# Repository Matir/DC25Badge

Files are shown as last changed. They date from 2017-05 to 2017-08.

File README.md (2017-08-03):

## Matir's DEF CON 25 Badge ##

This is an unofficial badge I made for DEF CON 25.  It's a blinding party-style
badge with 48 individually addressable RGB LEDs.  Off an adequate battery (a
medium LiPo) you can run all lights at max brightness, but that is *bright*.

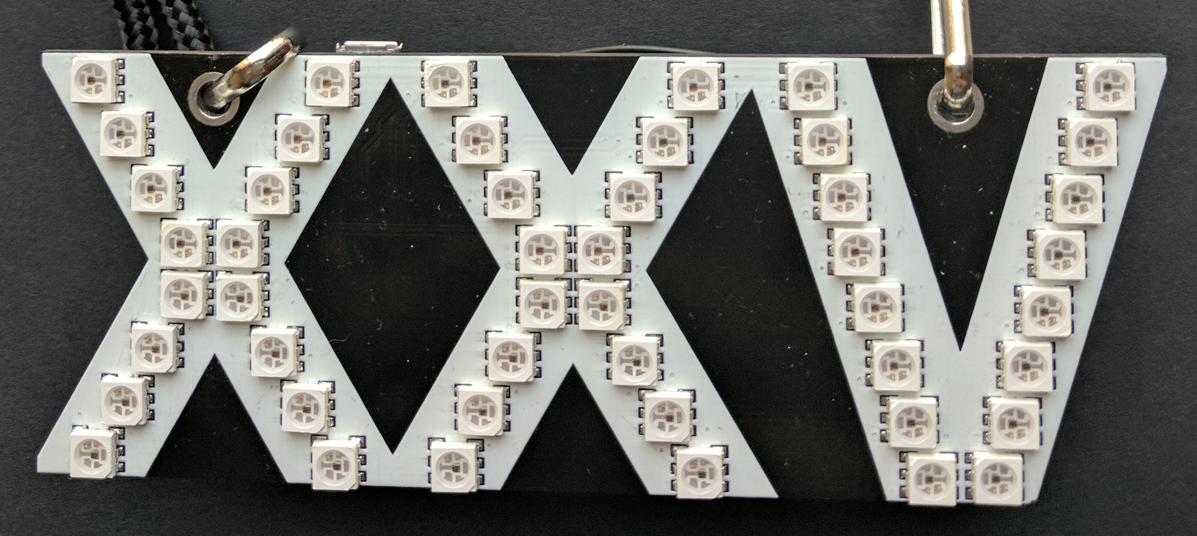
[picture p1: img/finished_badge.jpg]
Finished Badge


This is intended as a one-time release for others to learn from and/or remix the
firmware.  I don't plan to take pull requests since it will be over and I'll be
on to another project by the release.  :)

### PCB ###

The PCB was designed using Kicad.  Source files are in the `dc25badge/`
directory.

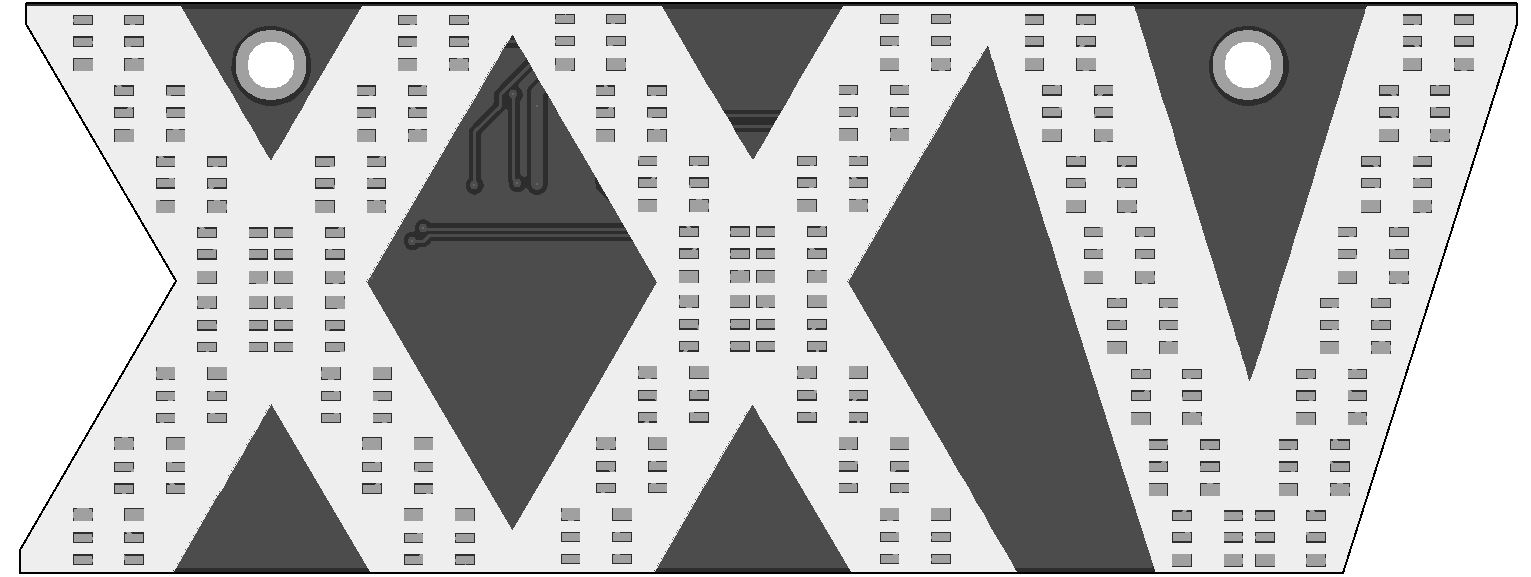
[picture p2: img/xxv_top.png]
PCB Rendering


### Compiling Firmware ###

To build the firmware, you'll need 3 things: this git repository, the Atmel
Software Framework (ASF), and an ARM compiler.  On Debian & Ubuntu, you'll want
to install the packages `gcc-arm-none-eabi` and `binutils-arm-none-eabi`.

`setup.sh` in the `src/` directory will get you the latest build of the ASF (at
least, it worked when this was prepared).  Running `make` will build the
firmware image.

To choose which patterns are available by pushing the mode button, edit the
array in `pattern.c`.

### Uploading Firmware ###

To upload a firmware image, you'll need to get into the bootloader.  To do this,
"double tap" the reset button, and the reset LED will stay solid green.  (If it
doesn't, you're not in the bootloader.)

You can then use `bossa` or just run `make upload` from the `src/` directory to
upload the current firmware build.

This is not an official Google product.

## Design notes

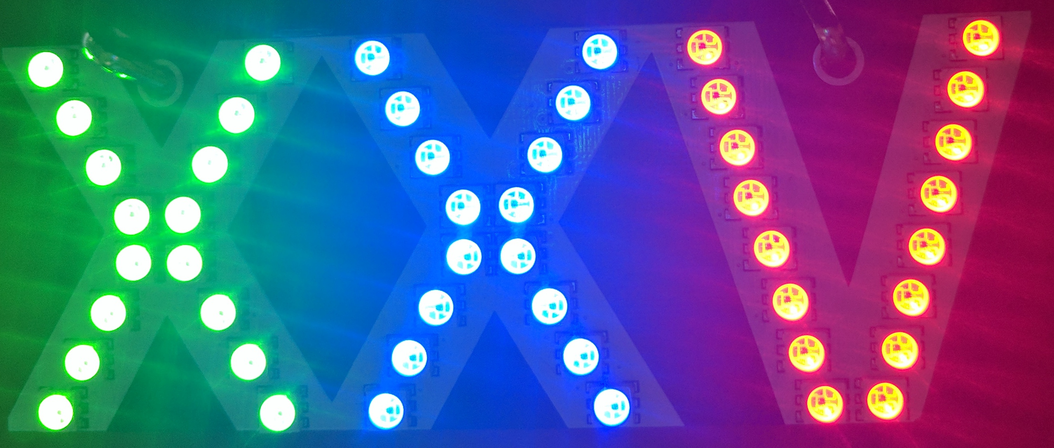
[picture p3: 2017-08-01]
img/lit_grb.jpg

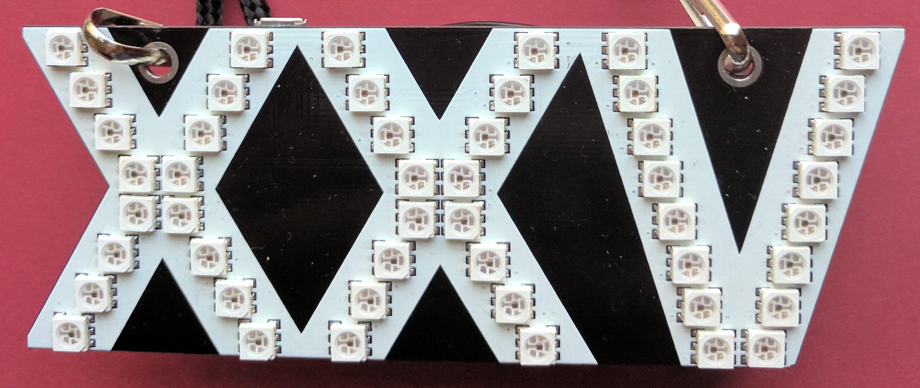
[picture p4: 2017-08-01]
img/finished_red.jpg

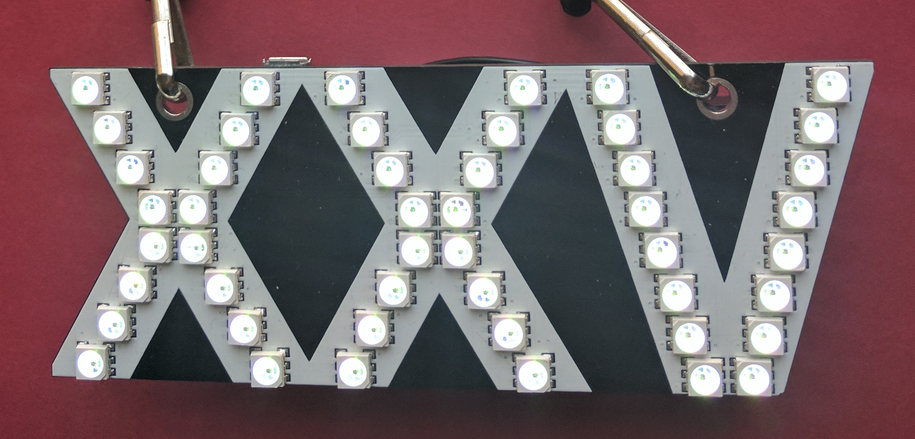
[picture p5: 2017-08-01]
img/lit_white.jpg

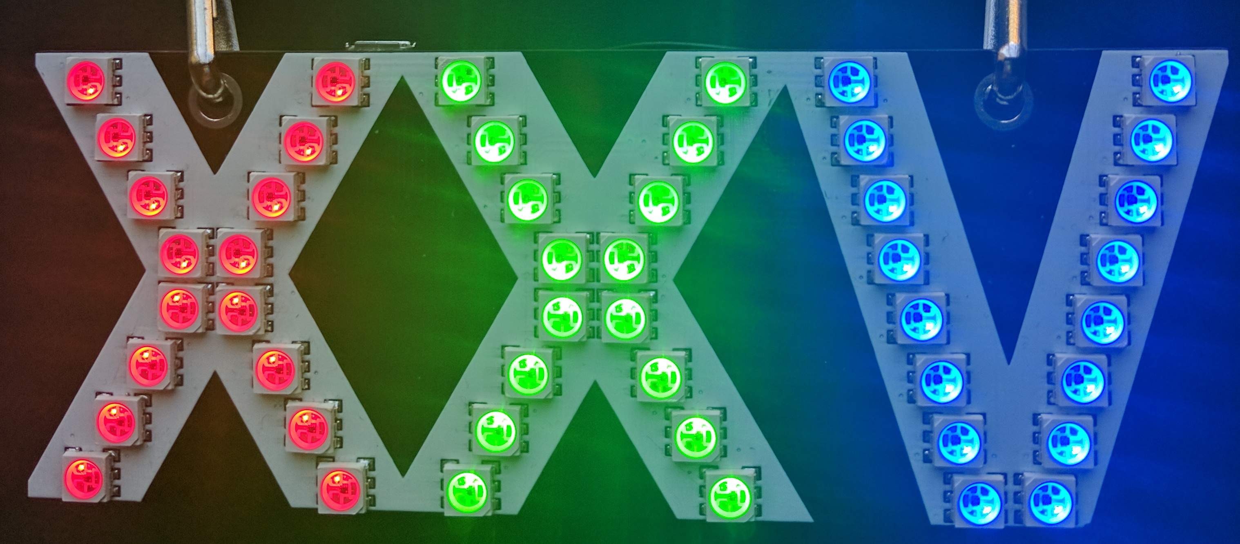
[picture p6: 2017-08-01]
img/lit_rgb.jpg

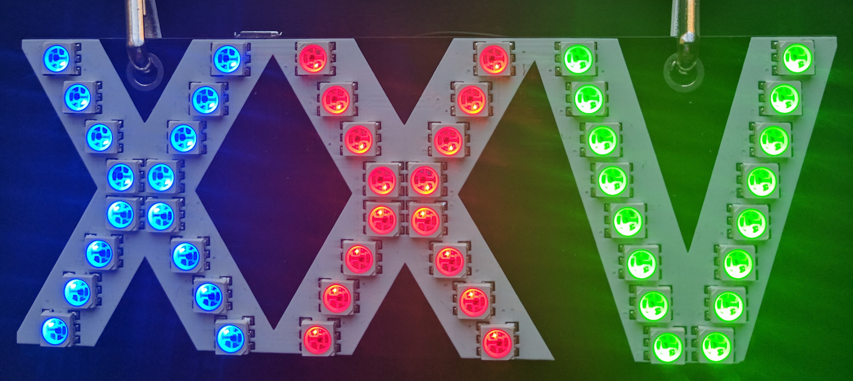
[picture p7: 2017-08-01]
img/lit_brg.jpg

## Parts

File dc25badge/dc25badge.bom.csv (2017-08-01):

Reference | Value | Footprint | Datasheet
U1 | MIC5305 | TO_SOT_Packages_SMD:SOT-23-5
P1 | BATT | Connectors_JST:JST_PH_S2B-PH-SM4-TB_02x2.00mm_Angled
C2 | 0.1u | Capacitors_SMD:C_0805
C1 | 1u | Capacitors_SMD:C_0805
C3 | 1u | Capacitors_SMD:C_0805
U3 | ATSAMD21E18A-AU | Housings_QFP:TQFP-32_7x7mm_Pitch0.8mm
C7 | 0.1u | Capacitors_SMD:C_0805
C9 | 0.1u | Capacitors_SMD:C_0805
C10 | 0.1u | Capacitors_SMD:C_0805
R6 | 10k | Resistors_SMD:R_0805
C11 | 10u | Capacitors_SMD:C_0805
C8 | 0.1u | Capacitors_SMD:C_0805
R5 | 330 | Resistors_SMD:R_0805
SW1 | RESET | Buttons_Switches_SMD:SW_SPST_EVQP0
P3 | CORTEX | Pin_Headers2:Pin_Header_Straight_2x05_Pitch1.27mm_SMD
P2 | USB_OTG | Badge_Parts:Amphenol_10118192
U4 | 74AHCT125 | SMD_Packages:SOIC-14_N
W2 | 3v3 | Measurement_Points:Measurement_Point_Round-SMD-Pad_Big
W3 | 5v | Measurement_Points:Measurement_Point_Round-SMD-Pad_Big
Y1 | 32.768k | Crystals:Crystal_SMD_G8
C13 | 22pF | Capacitors_SMD:C_0603
C12 | 22pF | Capacitors_SMD:C_0603
SW3 | MODE | Buttons_Switches_SMD:SW_SPST_EVQP0
SW4 | BRIGHT | Buttons_Switches_SMD:SW_SPST_EVQP0
U2 | TPS61232 | Badge_Parts:PSON-10P
C5 | 0.1u | Capacitors_SMD:C_0805
L1 | 1uH | Badge_Parts:Inductor_6.5x6
C4 | 22u | Capacitors_SMD:C_0805
C6 | 22u | Capacitors_SMD:C_0805
C14 | 22u | Capacitors_SMD:C_0805
C27 | 22u | Capacitors_SMD:C_0805
R1 | 330 | Resistors_SMD:R_0805
D1 | LED | LEDs:LED_0805
Q1 | DMN1019USN | TO_SOT_Packages_SMD:SOT-23
C17 | 1u | Capacitors_SMD:C_0805
R2 | 330 | Resistors_SMD:R_0805
R3 | 330 | Resistors_SMD:R_0805
C23 | NP | Capacitors_SMD:C_0805
C28 | NP | Capacitors_SMD:C_0805
JP1 | Jumper_NO_Small | Badge_Parts:JP_SOLDER
U38 | APA102 | Badge_Parts:APA102
U44 | APA102 | Badge_Parts:APA102
U50 | APA102 | Badge_Parts:APA102
U56 | APA102 | Badge_Parts:APA102
U14 | APA102 | Badge_Parts:APA102
U20 | APA102 | Badge_Parts:APA102
U26 | APA102 | Badge_Parts:APA102
U32 | APA102 | Badge_Parts:APA102
U29 | APA102 | Badge_Parts:APA102
U23 | APA102 | Badge_Parts:APA102
U17 | APA102 | Badge_Parts:APA102
U11 | APA102 | Badge_Parts:APA102
U53 | APA102 | Badge_Parts:APA102
U47 | APA102 | Badge_Parts:APA102
U41 | APA102 | Badge_Parts:APA102
U35 | APA102 | Badge_Parts:APA102
U39 | APA102 | Badge_Parts:APA102
U45 | APA102 | Badge_Parts:APA102
U51 | APA102 | Badge_Parts:APA102
U57 | APA102 | Badge_Parts:APA102
U15 | APA102 | Badge_Parts:APA102
U21 | APA102 | Badge_Parts:APA102
U27 | APA102 | Badge_Parts:APA102
U33 | APA102 | Badge_Parts:APA102
U30 | APA102 | Badge_Parts:APA102
U24 | APA102 | Badge_Parts:APA102
U18 | APA102 | Badge_Parts:APA102
U12 | APA102 | Badge_Parts:APA102
U54 | APA102 | Badge_Parts:APA102
U48 | APA102 | Badge_Parts:APA102
U42 | APA102 | Badge_Parts:APA102
U36 | APA102 | Badge_Parts:APA102
U40 | APA102 | Badge_Parts:APA102
U46 | APA102 | Badge_Parts:APA102
U52 | APA102 | Badge_Parts:APA102
U58 | APA102 | Badge_Parts:APA102
U64 | APA102 | Badge_Parts:APA102
U22 | APA102 | Badge_Parts:APA102
U28 | APA102 | Badge_Parts:APA102
U34 | APA102 | Badge_Parts:APA102
U31 | APA102 | Badge_Parts:APA102
U25 | APA102 | Badge_Parts:APA102
U19 | APA102 | Badge_Parts:APA102
U61 | APA102 | Badge_Parts:APA102
U55 | APA102 | Badge_Parts:APA102
U49 | APA102 | Badge_Parts:APA102
U43 | APA102 | Badge_Parts:APA102
U37 | APA102 | Badge_Parts:APA102
C15 | 0.1u | Capacitors_SMD:C_0805
C16 | 0.1u | Capacitors_SMD:C_0805
C18 | 0.1u | Capacitors_SMD:C_0805
C19 | 0.1u | Capacitors_SMD:C_0805
C20 | 0.1u | Capacitors_SMD:C_0805
C21 | 0.1u | Capacitors_SMD:C_0805
C22 | 0.1u | Capacitors_SMD:C_0805
C24 | 0.1u | Capacitors_SMD:C_0805
C25 | 0.1u | Capacitors_SMD:C_0805
C26 | 0.1u | Capacitors_SMD:C_0805

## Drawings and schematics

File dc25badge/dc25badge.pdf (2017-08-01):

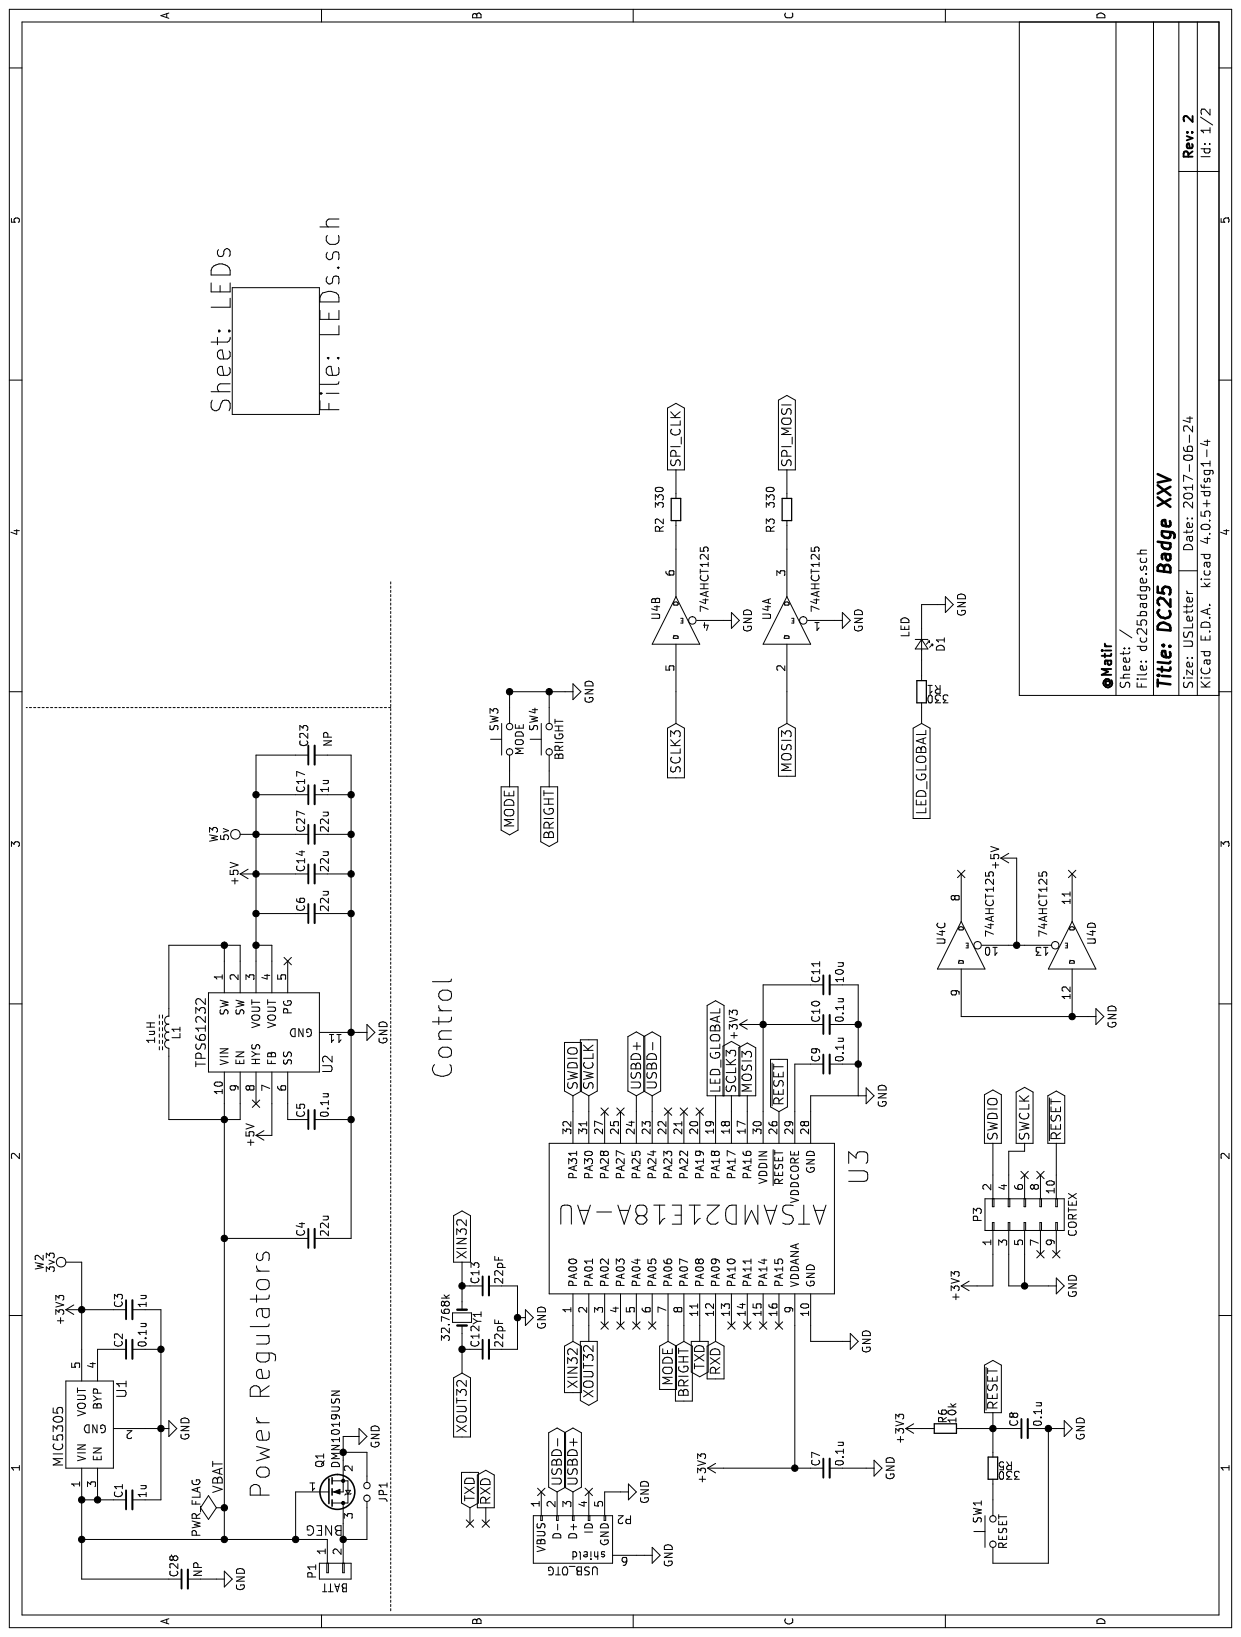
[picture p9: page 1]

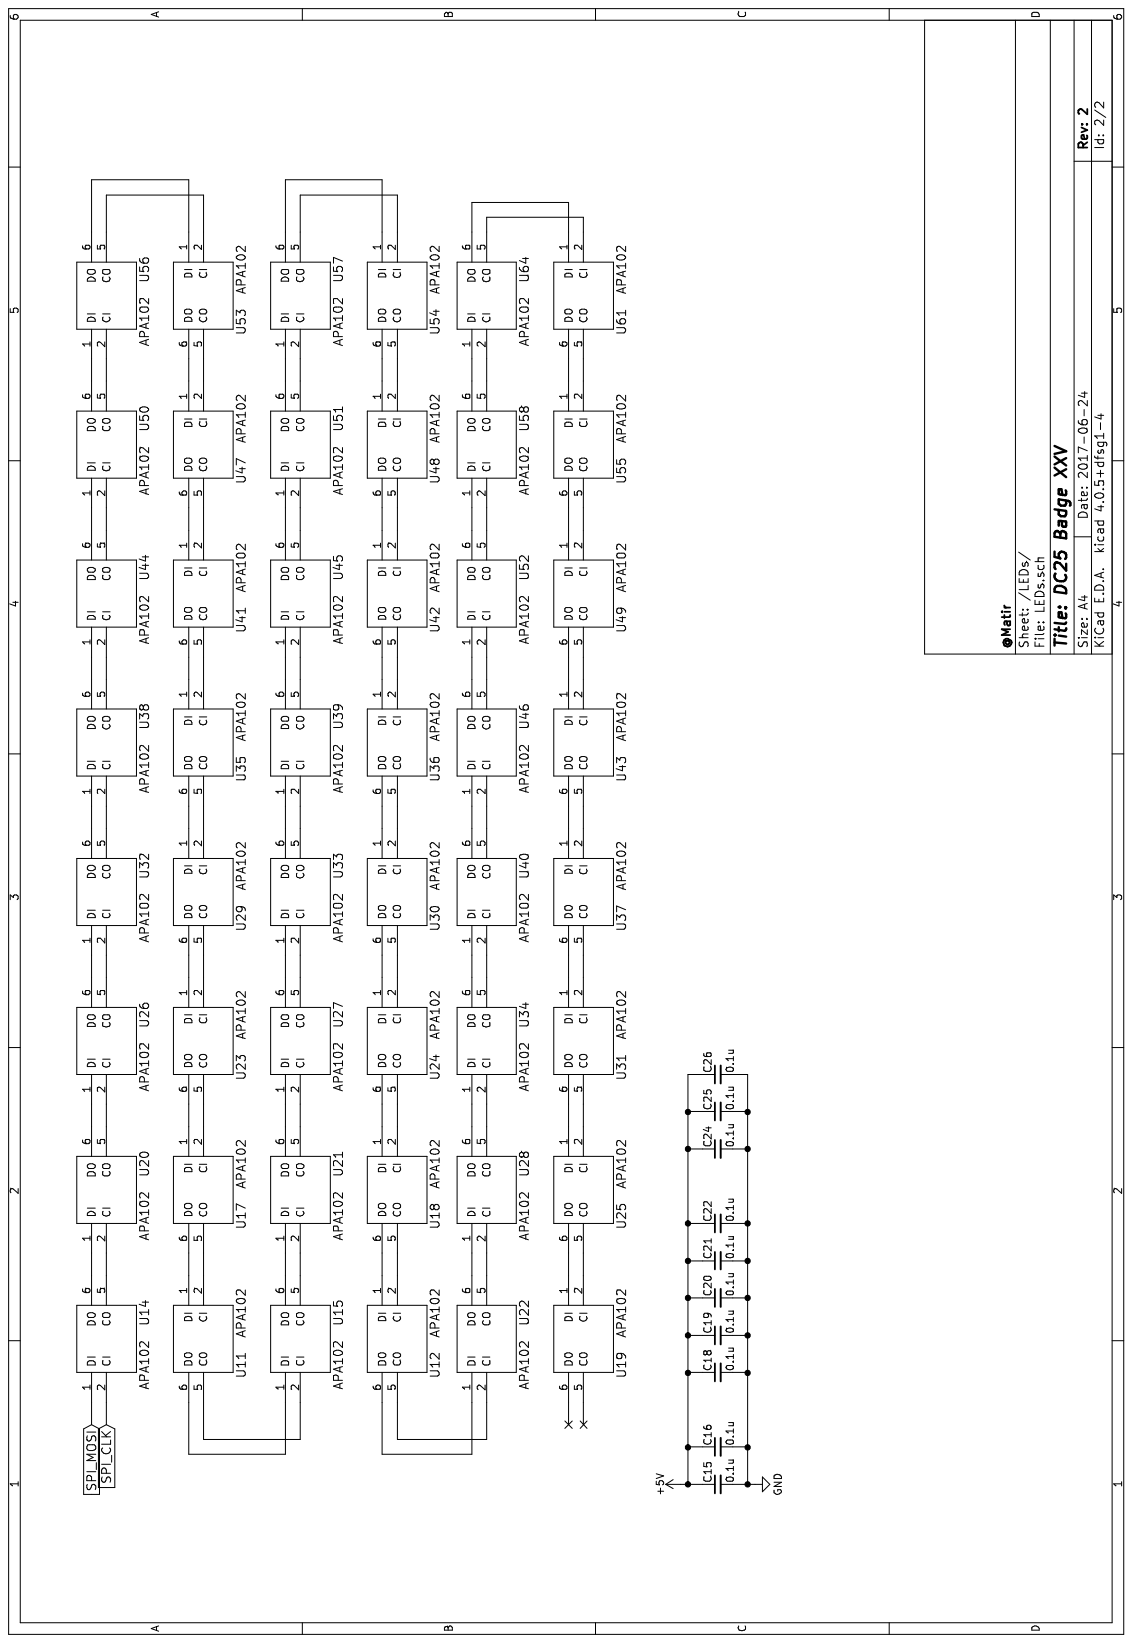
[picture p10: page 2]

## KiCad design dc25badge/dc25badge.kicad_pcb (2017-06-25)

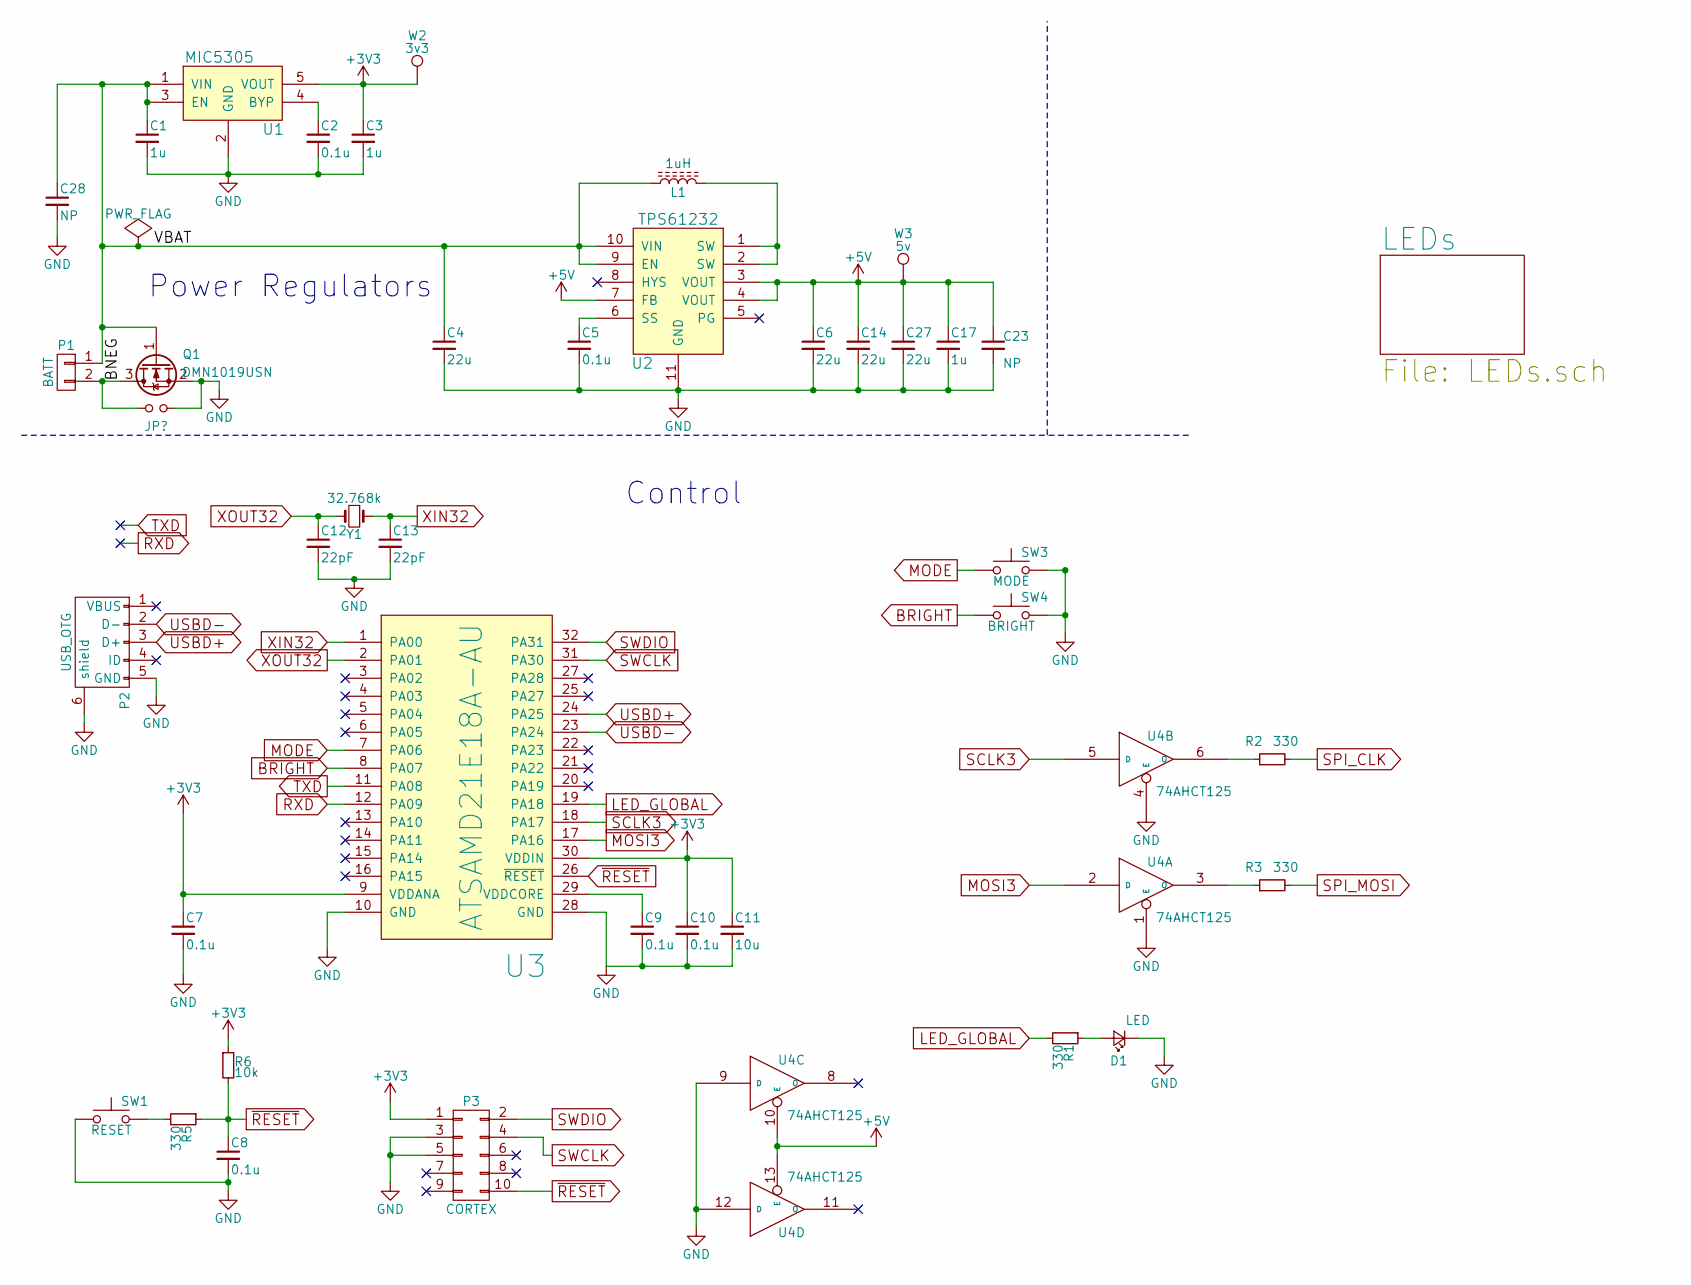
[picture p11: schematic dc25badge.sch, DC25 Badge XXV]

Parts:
C1, C3, C17: 1u; C_0805
C2, C5, C7, C8, C9, C10: 0.1u; C_0805
C4, C6, C14, C27: 22u; C_0805
C11: 10u; C_0805
C12, C13: 22pF; C_0603
C23, C28: NP; C_0805
D1: LED; LED_0805
L1: 1uH; Inductor_6.5x6
P1: BATT; JST_PH_S2B-PH-SM4-TB_02x2.00mm_Angled
P2: USB_OTG; Amphenol_10118192
P3: CORTEX; Pin_Header_Straight_2x05_Pitch1.27mm_SMD
Q1: DMN1019USN; SOT-23
R1, R2, R3, R5: 330; R_0805
R6: 10k; R_0805
SW1: RESET; SW_SPST_EVQP0
SW3: MODE; SW_SPST_EVQP0
SW4: BRIGHT; SW_SPST_EVQP0
U1: MIC5305; SOT-23-5
U2: TPS61232; PSON-10P
U3: ATSAMD21E18A-AU; TQFP-32_7x7mm_Pitch0.8mm
U4: 74AHCT125; SOIC-14_N
W2: 3v3; Measurement_Point_Round-SMD-Pad_Big
W3: 5v; Measurement_Point_Round-SMD-Pad_Big
Y1: 32.768k; Crystal_SMD_G8

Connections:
+3V3: C3.1, C7.1, C10.1, C11.1, P3.1, R6.1, U1.5 (VOUT), U3.9 (VDDANA), U3.30 (VDDIN), W2.1
+5V: C6.1, C14.1, C17.1, C23.1, C27.1, U2.3 (VOUT), U2.4 (VOUT), U2.7 (FB), U4.10 (E), U4.13 (E), U4.14 (+5V), W3.1; also elsewhere on the board
/BNEG: P1.2, Q1.3 (D); also elsewhere on the board
/VBAT: C1.1, C4.1, C28.1, L1.1, P1.1, Q1.1 (G), U1.1 (VIN), U1.3 (EN), U2.9 (EN), U2.10 (VIN)
BRIGHT: SW4.1, U3.8 (PA07)
GND: C1.2, C2.2, C3.2, C4.2, C5.2, C6.2, C7.2, C8.2, C9.2, C10.2, C11.2, C12.2, C13.2, C14.2, C17.2, C23.2, C27.2, C28.2, D1.1 (K), P2.5 (GND), P2.6 (shield), P3.3, P3.5, Q1.2 (S), SW1.1, SW3.2, SW4.2, U1.2 (GND), U2.11 (GND), U3.10 (GND), U3.28 (GND), U4.1 (E), U4.4 (E), U4.7 (GND), U4.9 (D), U4.12 (D); also elsewhere on the board
LED_GLOBAL: R1.2, U3.19 (PA18)
MODE: SW3.1, U3.7 (PA06)
MOSI3: U3.17 (PA16), U4.2 (D)
unnamed: C2.1, U1.4 (BYP)
unnamed: C5.1, U2.6 (SS)
unnamed: C9.1, U3.29 (VDDCORE)
unnamed: D1.2 (A), R1.1
unnamed: L1.2, U2.1 (SW), U2.2 (SW)
unnamed: R2.1, U4.6 (O)
unnamed: R3.1, U4.3 (O)
unnamed: R5.2, SW1.2
RXD: U3.12 (PA09)
SCLK3: U3.18 (PA17), U4.5 (D)
SPI_CLK: R2.2; also elsewhere on the board
SPI_MOSI: R3.2; also elsewhere on the board
SWCLK: P3.4, U3.31 (PA30)
SWDIO: P3.2, U3.32 (PA31)
TXD: U3.11 (PA08)
USBD+: P2.3 (D+), U3.24 (PA25)
USBD-: P2.2 (D-), U3.23 (PA24)
XIN32: C13.1, U3.1 (PA00), Y1.1
XOUT32: C12.1, U3.2 (PA01), Y1.2
~RESET: C8.1, P3.10, R5.1, R6.2, U3.26 (~RESET)

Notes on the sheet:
Power Regulators
Control

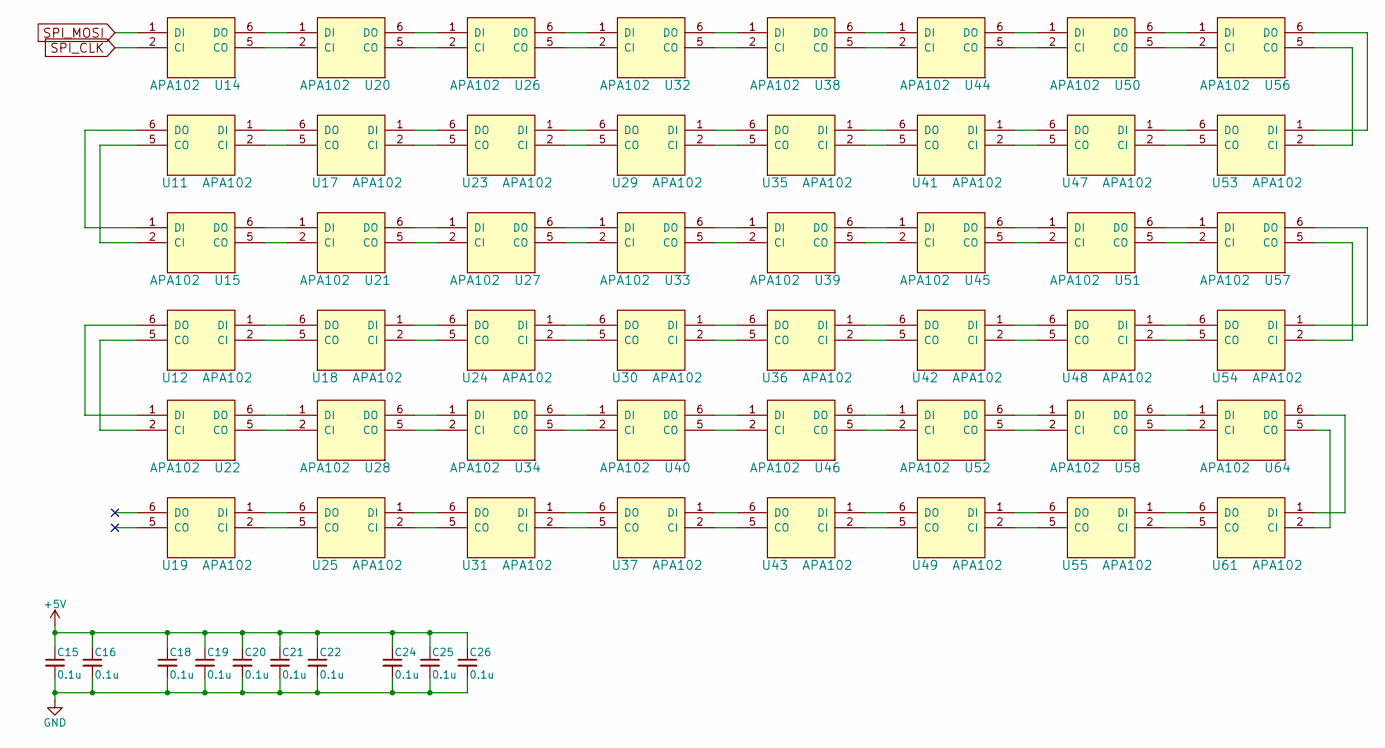
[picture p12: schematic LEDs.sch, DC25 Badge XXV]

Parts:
C15, C16, C18, C19, C20, C21, C22, C24, C25, C26: 0.1u; C_0805
U11, U12, U14, U15, U17, U18, U19, U20, U21, U22, U23, U24, U25, U26, U27, U28, U29, U30, U31, U32, U33, U34, U35, U36, U37, U38, U39, U40, U41, U42, U43, U44, U45, U46, U47, U48, U49, U50, U51, U52, U53, U54, U55, U56, U57, U58, U61, U64: APA102

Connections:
+5V: C15.1, C16.1, C18.1, C19.1, C20.1, C21.1, C22.1, C24.1, C25.1, C26.1, U11.4 (+5V), U12.4 (+5V), U14.4 (+5V), U15.4 (+5V), U17.4 (+5V), U18.4 (+5V), U19.4 (+5V), U20.4 (+5V), U21.4 (+5V), U22.4 (+5V), U23.4 (+5V), U24.4 (+5V), U25.4 (+5V), U26.4 (+5V), U27.4 (+5V), U28.4 (+5V), U29.4 (+5V), U30.4 (+5V), U31.4 (+5V), U32.4 (+5V), U33.4 (+5V), U34.4 (+5V), U35.4 (+5V), U36.4 (+5V), U37.4 (+5V), U38.4 (+5V), U39.4 (+5V), U40.4 (+5V), U41.4 (+5V), U42.4 (+5V), U43.4 (+5V), U44.4 (+5V), U45.4 (+5V), U46.4 (+5V), U47.4 (+5V), U48.4 (+5V), U49.4 (+5V), U50.4 (+5V), U51.4 (+5V), U52.4 (+5V), U53.4 (+5V), U54.4 (+5V), U55.4 (+5V), U56.4 (+5V), U57.4 (+5V), U58.4 (+5V), U61.4 (+5V), U64.4 (+5V); also elsewhere on the board
GND: C15.2, C16.2, C18.2, C19.2, C20.2, C21.2, C22.2, C24.2, C25.2, C26.2, U11.3 (GND), U12.3 (GND), U14.3 (GND), U15.3 (GND), U17.3 (GND), U18.3 (GND), U19.3 (GND), U20.3 (GND), U21.3 (GND), U22.3 (GND), U23.3 (GND), U24.3 (GND), U25.3 (GND), U26.3 (GND), U27.3 (GND), U28.3 (GND), U29.3 (GND), U30.3 (GND), U31.3 (GND), U32.3 (GND), U33.3 (GND), U34.3 (GND), U35.3 (GND), U36.3 (GND), U37.3 (GND), U38.3 (GND), U39.3 (GND), U40.3 (GND), U41.3 (GND), U42.3 (GND), U43.3 (GND), U44.3 (GND), U45.3 (GND), U46.3 (GND), U47.3 (GND), U48.3 (GND), U49.3 (GND), U50.3 (GND), U51.3 (GND), U52.3 (GND), U53.3 (GND), U54.3 (GND), U55.3 (GND), U56.3 (GND), U57.3 (GND), U58.3 (GND), U61.3 (GND), U64.3 (GND); also elsewhere on the board
unnamed: U11.1 (DI), U17.6 (DO)
unnamed: U11.2 (CI), U17.5 (CO)
unnamed: U11.5 (CO), U15.2 (CI)
unnamed: U11.6 (DO), U15.1 (DI)
unnamed: U12.1 (DI), U18.6 (DO)
unnamed: U12.2 (CI), U18.5 (CO)
unnamed: U12.5 (CO), U22.2 (CI)
unnamed: U12.6 (DO), U22.1 (DI)
unnamed: U14.5 (CO), U20.2 (CI)
unnamed: U14.6 (DO), U20.1 (DI)
unnamed: U15.5 (CO), U21.2 (CI)
unnamed: U15.6 (DO), U21.1 (DI)
unnamed: U17.1 (DI), U23.6 (DO)
unnamed: U17.2 (CI), U23.5 (CO)
unnamed: U18.1 (DI), U24.6 (DO)
unnamed: U18.2 (CI), U24.5 (CO)
unnamed: U19.1 (DI), U25.6 (DO)
unnamed: U19.2 (CI), U25.5 (CO)
unnamed: U20.5 (CO), U26.2 (CI)
unnamed: U20.6 (DO), U26.1 (DI)
unnamed: U21.5 (CO), U27.2 (CI)
unnamed: U21.6 (DO), U27.1 (DI)
unnamed: U22.5 (CO), U28.2 (CI)
unnamed: U22.6 (DO), U28.1 (DI)
unnamed: U23.1 (DI), U29.6 (DO)
unnamed: U23.2 (CI), U29.5 (CO)
unnamed: U24.1 (DI), U30.6 (DO)
unnamed: U24.2 (CI), U30.5 (CO)
unnamed: U25.1 (DI), U31.6 (DO)
unnamed: U25.2 (CI), U31.5 (CO)
unnamed: U26.5 (CO), U32.2 (CI)
unnamed: U26.6 (DO), U32.1 (DI)
unnamed: U27.5 (CO), U33.2 (CI)
unnamed: U27.6 (DO), U33.1 (DI)
unnamed: U28.5 (CO), U34.2 (CI)
unnamed: U28.6 (DO), U34.1 (DI)
unnamed: U29.1 (DI), U35.6 (DO)
unnamed: U29.2 (CI), U35.5 (CO)
unnamed: U30.1 (DI), U36.6 (DO)
unnamed: U30.2 (CI), U36.5 (CO)
unnamed: U31.1 (DI), U37.6 (DO)
unnamed: U31.2 (CI), U37.5 (CO)
unnamed: U32.5 (CO), U38.2 (CI)
unnamed: U32.6 (DO), U38.1 (DI)
unnamed: U33.5 (CO), U39.2 (CI)
unnamed: U33.6 (DO), U39.1 (DI)
unnamed: U34.5 (CO), U40.2 (CI)
unnamed: U34.6 (DO), U40.1 (DI)
unnamed: U35.1 (DI), U41.6 (DO)
unnamed: U35.2 (CI), U41.5 (CO)
unnamed: U36.1 (DI), U42.6 (DO)
unnamed: U36.2 (CI), U42.5 (CO)
unnamed: U37.1 (DI), U43.6 (DO)
unnamed: U37.2 (CI), U43.5 (CO)
unnamed: U38.5 (CO), U44.2 (CI)
unnamed: U38.6 (DO), U44.1 (DI)
unnamed: U39.5 (CO), U45.2 (CI)
unnamed: U39.6 (DO), U45.1 (DI)
unnamed: U40.5 (CO), U46.2 (CI)
unnamed: U40.6 (DO), U46.1 (DI)
unnamed: U41.1 (DI), U47.6 (DO)
unnamed: U41.2 (CI), U47.5 (CO)
unnamed: U42.1 (DI), U48.6 (DO)
unnamed: U42.2 (CI), U48.5 (CO)
unnamed: U43.1 (DI), U49.6 (DO)
unnamed: U43.2 (CI), U49.5 (CO)
unnamed: U44.5 (CO), U50.2 (CI)
unnamed: U44.6 (DO), U50.1 (DI)
unnamed: U45.5 (CO), U51.2 (CI)
unnamed: U45.6 (DO), U51.1 (DI)
unnamed: U46.5 (CO), U52.2 (CI)
unnamed: U46.6 (DO), U52.1 (DI)
unnamed: U47.1 (DI), U53.6 (DO)
unnamed: U47.2 (CI), U53.5 (CO)
unnamed: U48.1 (DI), U54.6 (DO)
unnamed: U48.2 (CI), U54.5 (CO)
unnamed: U49.1 (DI), U55.6 (DO)
unnamed: U49.2 (CI), U55.5 (CO)
unnamed: U50.5 (CO), U56.2 (CI)
unnamed: U50.6 (DO), U56.1 (DI)
unnamed: U51.5 (CO), U57.2 (CI)
unnamed: U51.6 (DO), U57.1 (DI)
unnamed: U52.5 (CO), U58.2 (CI)
unnamed: U52.6 (DO), U58.1 (DI)
unnamed: U53.1 (DI), U56.6 (DO)
unnamed: U53.2 (CI), U56.5 (CO)
unnamed: U54.1 (DI), U57.6 (DO)
unnamed: U54.2 (CI), U57.5 (CO)
unnamed: U55.1 (DI), U61.6 (DO)
unnamed: U55.2 (CI), U61.5 (CO)
unnamed: U58.5 (CO), U64.2 (CI)
unnamed: U58.6 (DO), U64.1 (DI)
unnamed: U61.1 (DI), U64.6 (DO)
unnamed: U61.2 (CI), U64.5 (CO)
SPI_CLK: U14.2 (CI); also elsewhere on the board
SPI_MOSI: U14.1 (DI); also elsewhere on the board

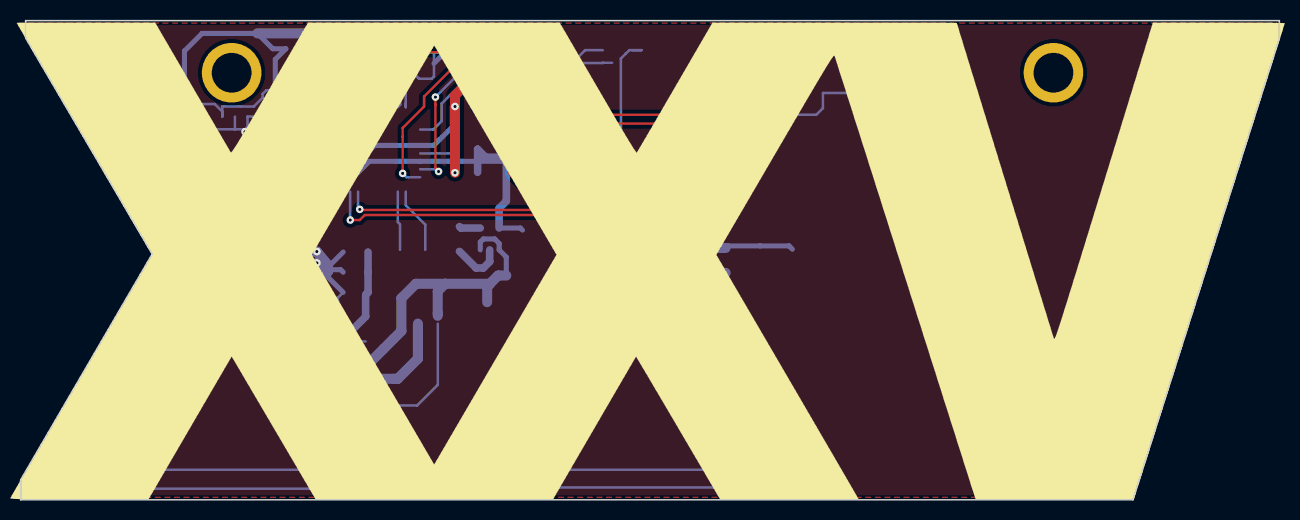
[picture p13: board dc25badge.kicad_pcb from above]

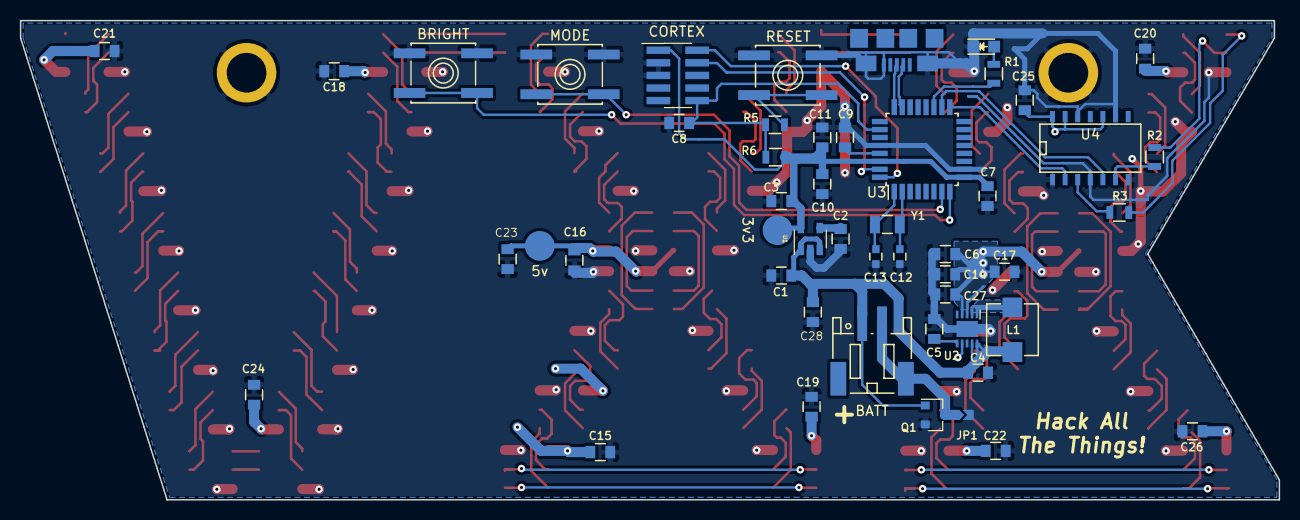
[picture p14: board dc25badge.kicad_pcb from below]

Board: 2 copper layers, 126.8 x 48.2 mm, 98 parts (50 on the bottom side), 121 nets.

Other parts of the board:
JP1: Jumper_NO_Small; JP_SOLDER

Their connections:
/BNEG: JP1.1; also elsewhere on the board
GND: JP1.2; also elsewhere on the board

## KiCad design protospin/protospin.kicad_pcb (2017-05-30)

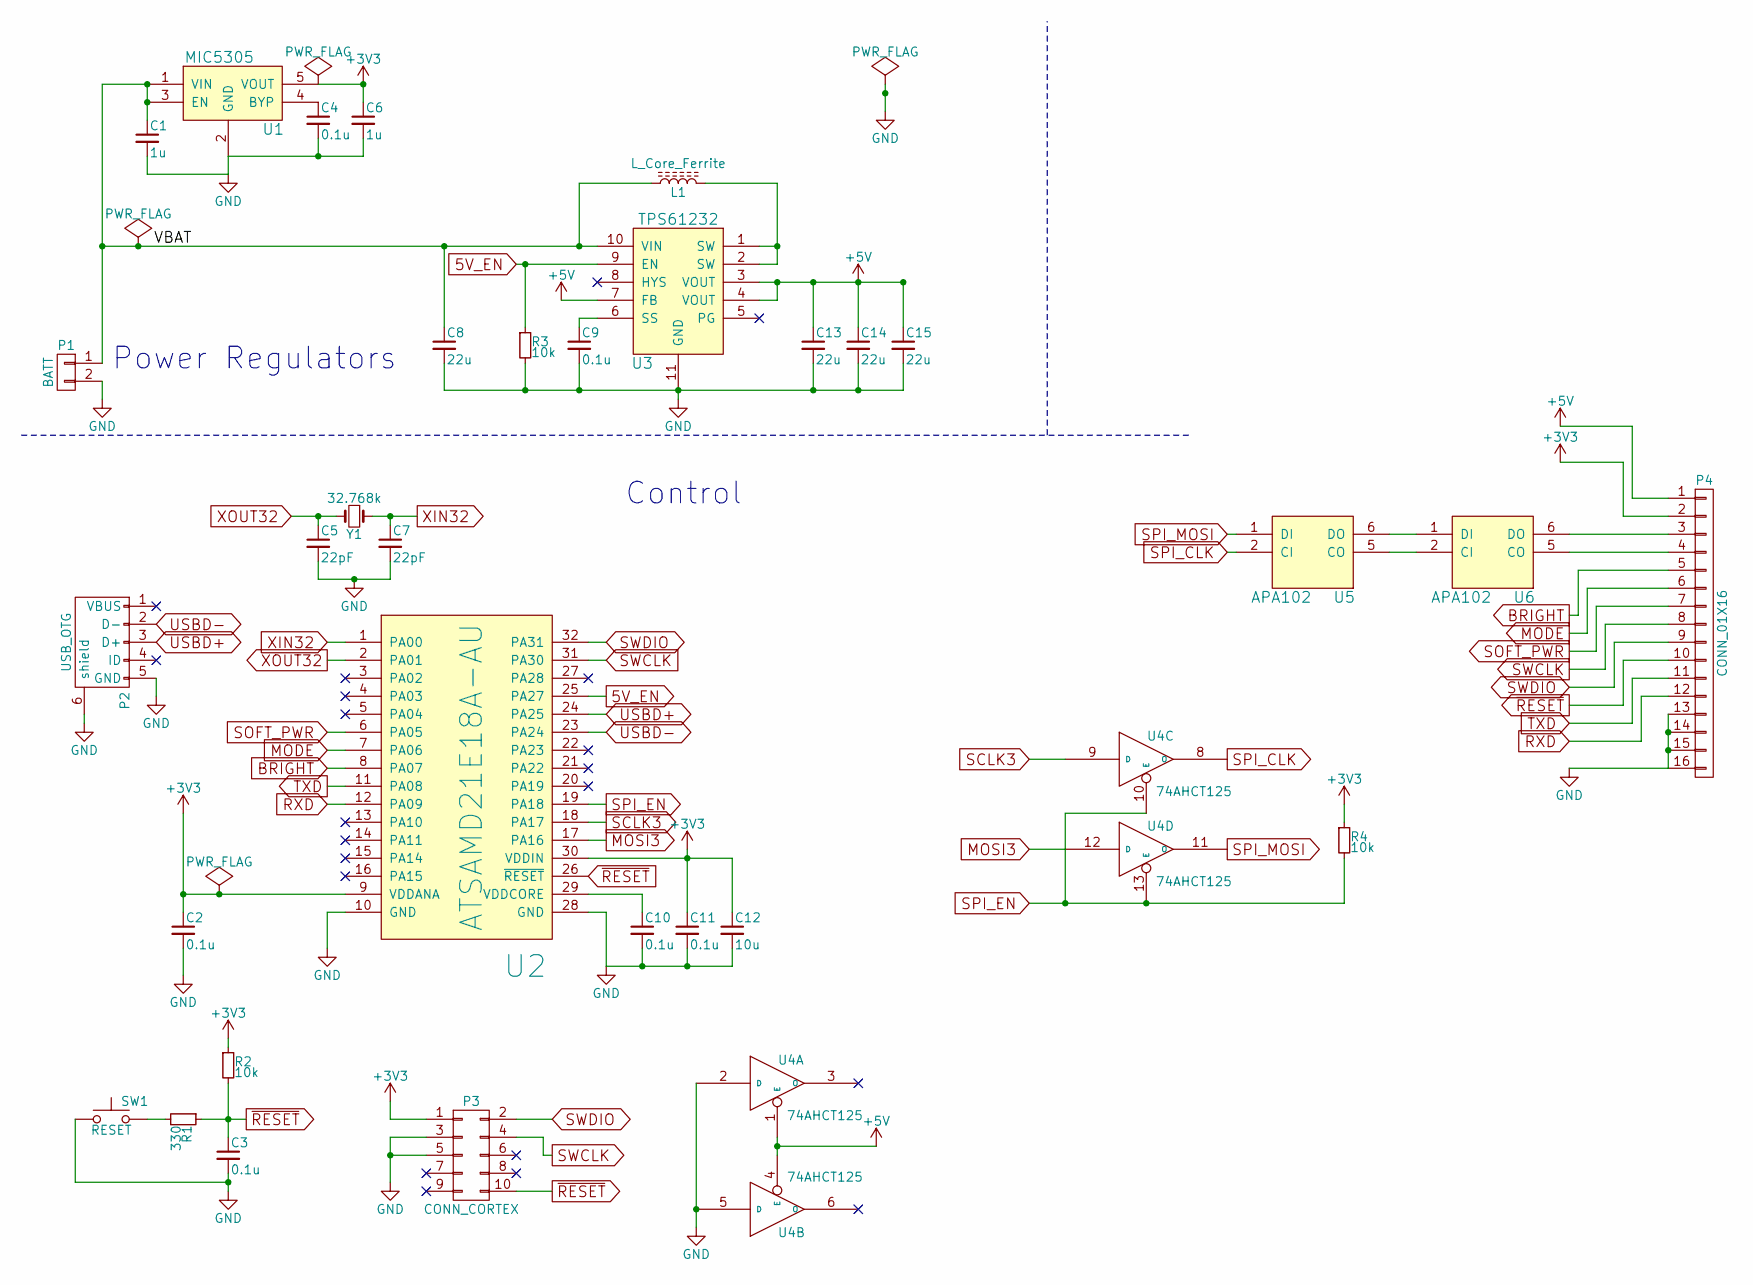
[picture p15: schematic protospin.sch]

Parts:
C1, C6: 1u; C_0805_HandSoldering
C2, C3, C4, C9, C10, C11: 0.1u; C_0805_HandSoldering
C5, C7: 22pF; C_0805_HandSoldering
C8, C13, C14, C15: 22u; C_0805_HandSoldering
C12: 10u; C_0805_HandSoldering
L1: L_Core_Ferrite; Inductor_6.5x6
P1: BATT; JST_PH_S2B-PH-SM4-TB_02x2.00mm_Angled
P2: USB_OTG; Amphenol_10118192
P3: CONN_CORTEX; Pin_Header_Straight_2x05_Pitch1.27mm_SMD
P4: CONN_01X16; Pin_Header_Straight_1x16_Pitch2.54mm_SMD_Pin1Right
R1: 330; R_0805_HandSoldering
R2, R3, R4: 10k; R_0805_HandSoldering
SW1: RESET; SW_SPST_EVQP0
U1: MIC5305; SOT-23-5
U2: ATSAMD21E18A-AU; TQFP-32_7x7mm_Pitch0.8mm
U3: TPS61232; PSON-10P
U4: 74AHCT125; SOIC-14_N
U5, U6: APA102
Y1: 32.768k; Crystal_SMD_G8

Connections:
5V_EN: R3.1, U2.25 (PA27), U3.9 (EN)
+3V3: C2.1, C6.1, C11.1, C12.1, P3.1, P4.2, R2.1, R4.1, U1.5 (VOUT), U2.9 (VDDANA), U2.30 (VDDIN)
+5V: C13.1, C14.1, C15.1, P4.1, U3.3 (VOUT), U3.4 (VOUT), U3.7 (FB), U4.1 (E), U4.4 (E), U4.14 (+5V), U5.4 (+5V), U6.4 (+5V)
/VBAT: C1.1, C8.1, L1.1, P1.1, U1.1 (VIN), U1.3 (EN), U3.10 (VIN)
BRIGHT: P4.5, U2.8 (PA07)
GND: C1.2, C2.2, C3.2, C4.2, C5.2, C6.2, C7.2, C8.2, C9.2, C10.2, C11.2, C12.2, C13.2, C14.2, C15.2, P1.2, P2.5 (GND), P2.6 (shield), P3.3, P3.5, P4.13, P4.14, P4.15, P4.16, R3.2, SW1.1, U1.2 (GND), U2.10 (GND), U2.28 (GND), U3.11 (GND), U4.2 (D), U4.5 (D), U4.7 (GND), U5.3 (GND), U6.3 (GND)
MODE: P4.6, U2.7 (PA06)
MOSI3: U2.17 (PA16), U4.12 (D)
unnamed: C4.1, U1.4 (BYP)
unnamed: C9.1, U3.6 (SS)
unnamed: C10.1, U2.29 (VDDCORE)
unnamed: L1.2, U3.1 (SW), U3.2 (SW)
unnamed: P4.3, U6.6 (DO)
unnamed: P4.4, U6.5 (CO)
unnamed: R1.2, SW1.2
unnamed: U5.5 (CO), U6.2 (CI)
unnamed: U5.6 (DO), U6.1 (DI)
RXD: P4.12, U2.12 (PA09)
SCLK3: U2.18 (PA17), U4.9 (D)
SOFT_PWR: P4.7, U2.6 (PA05)
SPI_CLK: U4.8 (O), U5.2 (CI)
SPI_EN: R4.2, U2.19 (PA18), U4.10 (E), U4.13 (E)
SPI_MOSI: U4.11 (O), U5.1 (DI)
SWCLK: P3.4, P4.8, U2.31 (PA30)
SWDIO: P3.2, P4.9, U2.32 (PA31)
TXD: P4.11, U2.11 (PA08)
USBD+: P2.3 (D+), U2.24 (PA25)
USBD-: P2.2 (D-), U2.23 (PA24)
XIN32: C7.1, U2.1 (PA00), Y1.1
XOUT32: C5.1, U2.2 (PA01), Y1.2
~RESET: C3.1, P3.10, P4.10, R1.1, R2.2, U2.26 (~RESET)

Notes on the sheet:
Power Regulators
Control

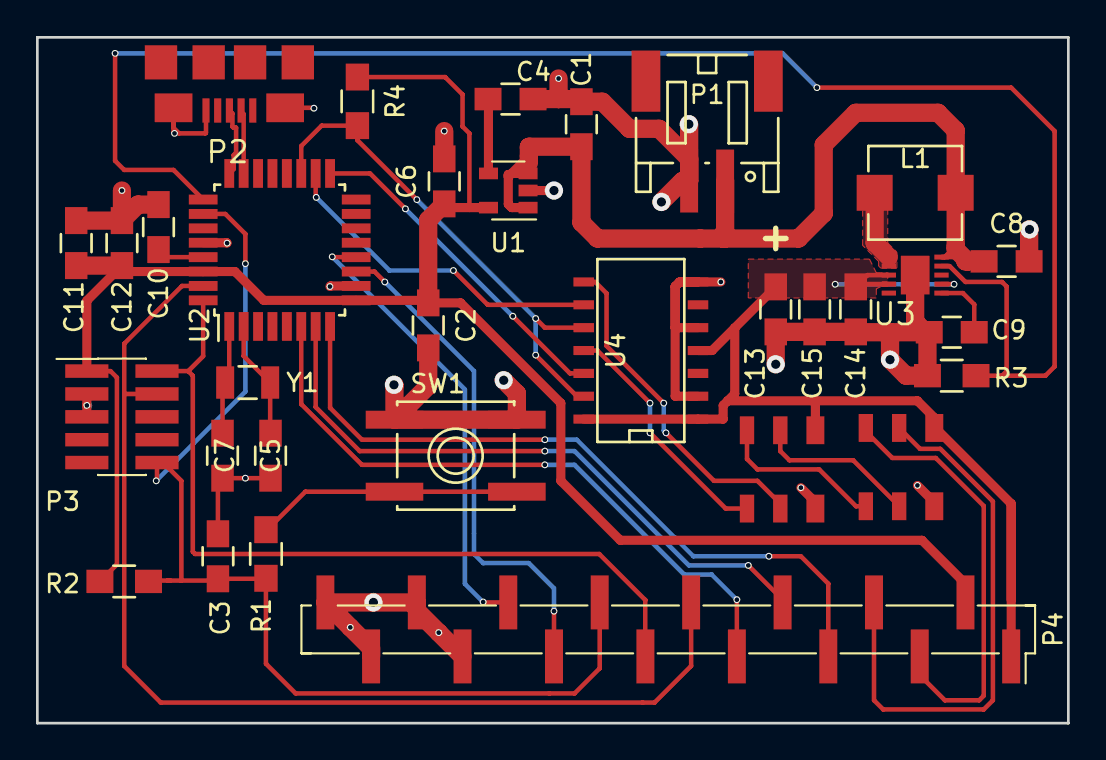
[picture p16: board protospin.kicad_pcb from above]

Board: 2 copper layers, 57.3 x 38.1 mm, 32 parts (0 on the bottom side), 31 nets.

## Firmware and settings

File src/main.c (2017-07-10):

/*
 * Copyright 2017 Google Inc.
 *
 * Licensed under the Apache License, Version 2.0 (the "License");
 * you may not use this file except in compliance with the License.
 * You may obtain a copy of the License at
 *
 *      http://www.apache.org/licenses/LICENSE-2.0
 *
 * Unless required by applicable law or agreed to in writing, software
 * distributed under the License is distributed on an "AS IS" BASIS,
 * WITHOUT WARRANTIES OR CONDITIONS OF ANY KIND, either express or implied.
 * See the License for the specific language governing permissions and
 * limitations under the License.
 */

#include "config.h"

// ASF Headers
#include <port.h>
#include <ioport.h>
#include <delay.h>
#include <sleepmgr.h>
#include <system.h>
#include <stdio_usb.h>
#include <pinmux.h>
#include <spi.h>
#include <status_codes.h>
#include <extint.h>
#include <extint_callback.h>

// Standard Headers
#include <stdio.h>

#include "apa102c/apa102c.h"
#include "pattern/pattern.h"
#include "button/button.h"


extern struct spi_module spi_master;
extern struct spi_slave_inst spi_slave_dev;

button_controller btn_bright;
button_controller btn_pattern;

static void setup();
static void setup_spi();
static void setup_buttons();
static void button_callback_pattern();
static void button_callback_bright();

#define LED_PIN_IO IOPORT_CREATE_PIN(IOPORT_PORTA, LED_PIN)

int main() {
  setup();
  // Blink LED to start process
  ioport_toggle_pin_level(LED_PIN_IO);
  delay_ms(250);
  ioport_toggle_pin_level(LED_PIN_IO);
  pattern_start();
}

static void setup() {
  system_init();
  irq_initialize_vectors();
  cpu_irq_enable();
  system_interrupt_enable_global();
  delay_init();
  sleepmgr_init();
  sleepmgr_lock_mode(SLEEPMGR_IDLE_2);  // This should work
  ioport_init();

  ioport_set_pin_dir(LED_PIN_IO, IOPORT_DIR_OUTPUT);

  // Redirect STDIO to the USB Port
  stdio_usb_init();
  // Disabled by default
  stdio_usb_disable();

  setup_spi();

  pattern_setup();

  setup_buttons();
}

static void setup_spi() {
  // Setup SPI on SERCOM1 with the following settings:
  // MOSI = SERCOM1:PAD0
  // SCK = SERCOM1:PAD3
  // CS = SERCOM1:PAD2 (AKA PA18)

  struct spi_config cfg;
#ifdef SS_PIN
  struct spi_slave_inst_config slave_cfg;

  spi_slave_inst_get_config_defaults(&slave_cfg);
  slave_cfg.ss_pin = PIN_PA18;
  spi_attach_slave(&spi_slave_dev, &slave_cfg);
#endif

  spi_get_config_defaults(&cfg);
#if defined(XBOARD_SPARKFUN)
  cfg.mux_setting = SPI_SIGNAL_MUX_SETTING_N;
  cfg.pinmux_pad0 = PINMUX_PA16C_SERCOM1_PAD0;
  cfg.pinmux_pad1 = PINMUX_UNUSED;
  cfg.pinmux_pad2 = PINMUX_PA18C_SERCOM1_PAD2;
  cfg.pinmux_pad3 = PINMUX_PA19C_SERCOM1_PAD3;
#elif defined(XBOARD_TEST)
  cfg.mux_setting = SPI_SIGNAL_MUX_SETTING_D;
  cfg.pinmux_pad0 = PINMUX_PA16C_SERCOM1_PAD0;
  cfg.pinmux_pad1 = PINMUX_PA17C_SERCOM1_PAD1;
  cfg.pinmux_pad2 = PINMUX_PA18C_SERCOM1_PAD2;
  cfg.pinmux_pad3 = PINMUX_UNUSED;
#elif defined(XBOARD_XXV)
  cfg.mux_setting = SPI_SIGNAL_MUX_SETTING_D;
  cfg.pinmux_pad0 = PINMUX_PA16C_SERCOM1_PAD0;
  cfg.pinmux_pad1 = PINMUX_PA17C_SERCOM1_PAD1;
  cfg.pinmux_pad2 = PINMUX_UNUSED;
  cfg.pinmux_pad3 = PINMUX_UNUSED;
#else
# error "Unknown board config."
#endif
  cfg.receiver_enable = false; // One way
  cfg.mode_specific.master.baudrate = SPI_SPEED;
  if (spi_init(&spi_master, SERCOM1, &cfg) != STATUS_OK )
  {
    printf("Failed to setup SPI instance.\r\n");
    return;
  }
  spi_enable(&spi_master);
}

void discard_stdin() {
  // Sigh, apparently the CDC mode is blocking.
  // This runs from interrupt context
  while (udi_cdc_is_rx_ready())
    getchar();
}

void terminal_connected(bool set) {
  // This is used to prevent blocking with a full buffer.
  // Requires a terminal with DTR capabilities
  if (set) {
    stdio_usb_enable();
  } else {
    stdio_usb_disable();
  }
}

static void setup_buttons() {
  struct extint_chan_conf config_int;

  // Setup pattern button
  extint_chan_get_config_defaults(&config_int);
  config_int.gpio_pin = PATTERN_BUTTON_PIN;
  config_int.gpio_pin_mux = PATTERN_BUTTON_MUX;
  config_int.gpio_pin_pull = EXTINT_PULL_UP;
  config_int.detection_criteria = EXTINT_DETECT_BOTH;
  extint_chan_set_config(PATTERN_BUTTON_PIN, &config_int);

  extint_register_callback(
      button_callback_pattern, PATTERN_BUTTON_PIN, EXTINT_CALLBACK_TYPE_DETECT);
  extint_chan_enable_callback(PATTERN_BUTTON_PIN, EXTINT_CALLBACK_TYPE_DETECT);

  button_debounce_default(&btn_pattern);
  btn_pattern.pin = PATTERN_BUTTON_PIN;
  btn_pattern.short_press_handler = pattern_next;
  btn_pattern.long_press_handler = pattern_shutdown;

  // Setup brightness button
  extint_chan_get_config_defaults(&config_int);
  config_int.gpio_pin = BRIGHT_BUTTON_PIN;
  config_int.gpio_pin_mux = BRIGHT_BUTTON_MUX;
  config_int.gpio_pin_pull = EXTINT_PULL_UP;
  config_int.detection_criteria = EXTINT_DETECT_BOTH;
  extint_chan_set_config(BRIGHT_BUTTON_PIN, &config_int);

  extint_register_callback(
      button_callback_bright, BRIGHT_BUTTON_PIN, EXTINT_CALLBACK_TYPE_DETECT);
  extint_chan_enable_callback(BRIGHT_BUTTON_PIN, EXTINT_CALLBACK_TYPE_DETECT);

  button_debounce_default(&btn_bright);
  btn_bright.pin = BRIGHT_BUTTON_PIN;
  btn_bright.short_press_handler = pattern_bright_cycle;
  btn_bright.long_press_handler = pattern_blind_toggle;

  // Start the debounce clock
  button_debounce_clock_setup();
}

static void button_callback_pattern() {
  button_event_handler(&btn_pattern);
}

static void button_callback_bright() {
  button_event_handler(&btn_bright);
}

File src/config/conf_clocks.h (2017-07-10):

/*
 * Copyright 2017 Google Inc.
 *
 * Licensed under the Apache License, Version 2.0 (the "License");
 * you may not use this file except in compliance with the License.
 * You may obtain a copy of the License at
 *
 *      http://www.apache.org/licenses/LICENSE-2.0
 *
 * Unless required by applicable law or agreed to in writing, software
 * distributed under the License is distributed on an "AS IS" BASIS,
 * WITHOUT WARRANTIES OR CONDITIONS OF ANY KIND, either express or implied.
 * See the License for the specific language governing permissions and
 * limitations under the License.
 */

#include <clock.h>

#ifndef CONF_CLOCKS_H_INCLUDED
#  define CONF_CLOCKS_H_INCLUDED

/* System clock bus configuration */
#  define CONF_CLOCK_FLASH_WAIT_STATES            2
#  define CONF_CLOCK_CPU_DIVIDER                  SYSTEM_MAIN_CLOCK_DIV_1
#  define CONF_CLOCK_APBA_DIVIDER                 SYSTEM_MAIN_CLOCK_DIV_1
#  define CONF_CLOCK_APBB_DIVIDER                 SYSTEM_MAIN_CLOCK_DIV_1
#  define CONF_CLOCK_APBC_DIVIDER                 SYSTEM_MAIN_CLOCK_DIV_1

/* SYSTEM_CLOCK_SOURCE_OSC8M configuration - Internal 8MHz oscillator */
#  define CONF_CLOCK_OSC8M_PRESCALER              SYSTEM_OSC8M_DIV_1
#  define CONF_CLOCK_OSC8M_ON_DEMAND              true
#  define CONF_CLOCK_OSC8M_RUN_IN_STANDBY         true

/* SYSTEM_CLOCK_SOURCE_XOSC configuration - External clock/oscillator */
#  define CONF_CLOCK_XOSC_ENABLE                  false
#  define CONF_CLOCK_XOSC_EXTERNAL_CRYSTAL        SYSTEM_CLOCK_EXTERNAL_CRYSTAL
#  define CONF_CLOCK_XOSC_EXTERNAL_FREQUENCY      12000000UL
#  define CONF_CLOCK_XOSC_STARTUP_TIME            SYSTEM_XOSC_STARTUP_32768
#  define CONF_CLOCK_XOSC_AUTO_GAIN_CONTROL       true
#  define CONF_CLOCK_XOSC_ON_DEMAND               true
#  define CONF_CLOCK_XOSC_RUN_IN_STANDBY          false

/* SYSTEM_CLOCK_SOURCE_XOSC32K configuration - External 32KHz crystal/clock oscillator */
#  define CONF_CLOCK_XOSC32K_ENABLE               false
#  define CONF_CLOCK_XOSC32K_EXTERNAL_CRYSTAL     SYSTEM_CLOCK_EXTERNAL_CRYSTAL
#  define CONF_CLOCK_XOSC32K_STARTUP_TIME         SYSTEM_XOSC32K_STARTUP_65536
#  define CONF_CLOCK_XOSC32K_AUTO_AMPLITUDE_CONTROL  false
#  define CONF_CLOCK_XOSC32K_ENABLE_1KHZ_OUPUT    false
#  define CONF_CLOCK_XOSC32K_ENABLE_32KHZ_OUTPUT  true
#  define CONF_CLOCK_XOSC32K_ON_DEMAND            true
#  define CONF_CLOCK_XOSC32K_RUN_IN_STANDBY       false

/* SYSTEM_CLOCK_SOURCE_OSC32K configuration - Internal 32KHz oscillator */
#  define CONF_CLOCK_OSC32K_ENABLE                false
#  define CONF_CLOCK_OSC32K_STARTUP_TIME          SYSTEM_OSC32K_STARTUP_130
#  define CONF_CLOCK_OSC32K_ENABLE_1KHZ_OUTPUT    true
#  define CONF_CLOCK_OSC32K_ENABLE_32KHZ_OUTPUT   true
#  define CONF_CLOCK_OSC32K_ON_DEMAND             true
#  define CONF_CLOCK_OSC32K_RUN_IN_STANDBY        false

/* SYSTEM_CLOCK_SOURCE_DFLL configuration - Digital Frequency Locked Loop */
#  define CONF_CLOCK_DFLL_ENABLE                  true
#  define CONF_CLOCK_DFLL_LOOP_MODE               SYSTEM_CLOCK_DFLL_LOOP_MODE_USB_RECOVERY
#  define CONF_CLOCK_DFLL_ON_DEMAND               true

/* DFLL open loop mode configuration */
/* NOT USED in USB Mode */
#  define CONF_CLOCK_DFLL_COARSE_VALUE            (0x1f / 4)
#  define CONF_CLOCK_DFLL_FINE_VALUE              (0xff / 4)

/* DFLL closed loop mode configuration */
/* NOT USED in USB Mode */
#  define CONF_CLOCK_DFLL_SOURCE_GCLK_GENERATOR   GCLK_GENERATOR_1
#  define CONF_CLOCK_DFLL_MULTIPLY_FACTOR         1465 //(48000000 / 32768)
#  define CONF_CLOCK_DFLL_QUICK_LOCK              true
#  define CONF_CLOCK_DFLL_TRACK_AFTER_FINE_LOCK   true
#  define CONF_CLOCK_DFLL_KEEP_LOCK_ON_WAKEUP     true
#  define CONF_CLOCK_DFLL_ENABLE_CHILL_CYCLE      true
#  define CONF_CLOCK_DFLL_MAX_COARSE_STEP_SIZE    (0x1f / 4)
#  define CONF_CLOCK_DFLL_MAX_FINE_STEP_SIZE      (0xff / 4)

/* SYSTEM_CLOCK_SOURCE_DPLL configuration - Digital Phase-Locked Loop */
#  define CONF_CLOCK_DPLL_ENABLE                  true
#  define CONF_CLOCK_DPLL_ON_DEMAND               true
#  define CONF_CLOCK_DPLL_RUN_IN_STANDBY          true
#  define CONF_CLOCK_DPLL_LOCK_BYPASS             false
#  define CONF_CLOCK_DPLL_WAKE_UP_FAST            false
#  define CONF_CLOCK_DPLL_LOW_POWER_ENABLE        false

#  define CONF_CLOCK_DPLL_LOCK_TIME               SYSTEM_CLOCK_SOURCE_DPLL_LOCK_TIME_DEFAULT
#  define CONF_CLOCK_DPLL_REFERENCE_CLOCK         SYSTEM_CLOCK_SOURCE_DPLL_REFERENCE_CLOCK_GCLK
#  define CONF_CLOCK_DPLL_FILTER                  SYSTEM_CLOCK_SOURCE_DPLL_FILTER_DEFAULT

#  define CONF_CLOCK_DPLL_REFERENCE_FREQUENCY     1000000
#  define CONF_CLOCK_DPLL_REFERENCE_DIVIDER       1
#  define CONF_CLOCK_DPLL_OUTPUT_FREQUENCY        48000000

/* DPLL GCLK reference configuration */
#  define CONF_CLOCK_DPLL_REFERENCE_GCLK_GENERATOR  GCLK_GENERATOR_1
/* DPLL GCLK lock timer configuration */
#  define CONF_CLOCK_DPLL_LOCK_GCLK_GENERATOR     GCLK_GENERATOR_1

/* Set this to true to configure the GCLK when running clocks_init. If set to
 * false, none of the GCLK generators will be configured in clocks_init(). */
#  define CONF_CLOCK_CONFIGURE_GCLK               true

/* Configure GCLK generator 0 (Main Clock) */
#  define CONF_CLOCK_GCLK_0_ENABLE                true
#  define CONF_CLOCK_GCLK_0_RUN_IN_STANDBY        true
#  define CONF_CLOCK_GCLK_0_CLOCK_SOURCE          SYSTEM_CLOCK_SOURCE_DPLL
#  define CONF_CLOCK_GCLK_0_PRESCALER             1
#  define CONF_CLOCK_GCLK_0_OUTPUT_ENABLE         false

/* Configure GCLK generator 1 */
#  define CONF_CLOCK_GCLK_1_ENABLE                true
#  define CONF_CLOCK_GCLK_1_RUN_IN_STANDBY        true
#  define CONF_CLOCK_GCLK_1_CLOCK_SOURCE          SYSTEM_CLOCK_SOURCE_OSC8M
#  define CONF_CLOCK_GCLK_1_PRESCALER             8
#  define CONF_CLOCK_GCLK_1_OUTPUT_ENABLE         false

/* Configure GCLK generator 2 (RTC) */
#  define CONF_CLOCK_GCLK_2_ENABLE                false
#  define CONF_CLOCK_GCLK_2_RUN_IN_STANDBY        false
#  define CONF_CLOCK_GCLK_2_CLOCK_SOURCE          SYSTEM_CLOCK_SOURCE_OSC32K
#  define CONF_CLOCK_GCLK_2_PRESCALER             32
#  define CONF_CLOCK_GCLK_2_OUTPUT_ENABLE         false

/* Configure GCLK generator 3 */
#  define CONF_CLOCK_GCLK_3_ENABLE                true
#  define CONF_CLOCK_GCLK_3_RUN_IN_STANDBY        false
#  define CONF_CLOCK_GCLK_3_CLOCK_SOURCE          SYSTEM_CLOCK_SOURCE_DFLL
#  define CONF_CLOCK_GCLK_3_PRESCALER             1
#  define CONF_CLOCK_GCLK_3_OUTPUT_ENABLE         false

/* Configure GCLK generator 4 */
#  define CONF_CLOCK_GCLK_4_ENABLE                false
#  define CONF_CLOCK_GCLK_4_RUN_IN_STANDBY        false
#  define CONF_CLOCK_GCLK_4_CLOCK_SOURCE          SYSTEM_CLOCK_SOURCE_OSC8M
#  define CONF_CLOCK_GCLK_4_PRESCALER             1
#  define CONF_CLOCK_GCLK_4_OUTPUT_ENABLE         false
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

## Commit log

2017-05-28 First pass at schematic.
    [LEDs.sch, dc25badge.kicad_pcb, dc25badge.sch]
2017-05-28 First letter routed.
    [LEDs.sch, dc25badge.bom.csv, dc25badge.sch]
2017-05-28 Layout all LEDs.
    [dc25badge.kicad_pcb]
2017-05-29 Routed 1 letter.
    [dc25badge.kicad_pcb]
2017-05-29 More routing.
    [dc25badge.kicad_pcb]
2017-05-29 More more routing.
    [dc25badge.kicad_pcb]
2017-05-29 Route all letters.
    [dc25badge.kicad_pcb]
2017-05-29 remove old PS.
    [dc25badge.kicad_pcb, dc25badge.sch]
2017-05-29 schematic for new PS.
    [LEDs.sch, dc25badge.sch]
2017-05-29 add PS to board.
    [dc25badge.kicad_pcb]
2017-05-29 Before routing back.
    [LEDs.sch, dc25badge.kicad_pcb, dc25badge.sch]
2017-05-29 Full routing.
    [LEDs.sch, dc25badge.kicad_pcb, dc25badge.sch]
2017-05-29 PCB roll 1.
    [dc25badge.kicad_pcb]
2017-05-29 Build a small prototype board.
    [protospin.kicad_pcb, protospin.sch]
2017-05-29 Fix battery error.
    [dc25badge.kicad_pcb, dc25badge.sch]
2017-05-30 Switch to 0603 caps on oscillator.
    [dc25badge.bom.csv, dc25badge.kicad_pcb, dc25badge.sch]
2017-05-30 Rev A protospin.
    [protospin-B.Cu.gbr, protospin-B.Mask.gbr, protospin-B.Paste.gbr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]
2017-05-30 Fixup trace clearances.
    [dc25badge.kicad_pcb]
2017-05-30 Move to 8mil mins.
    [dc25badge.kicad_pcb]
2017-05-30 Readd cuts.
    [dc25badge-B.Cu.gbr, dc25badge-B.Mask.gbr, dc25badge-B.SilkS.gbr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]
2017-05-30 Add dimensions.
    [dc25badge.kicad_pcb]
2017-05-30 Reduce solder mask clearance.
    [dc25badge-B.Cu.gbr, dc25badge-B.Mask.gbr, dc25badge-B.SilkS.gbr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]
2017-05-31 Add "Designed by @Matir" badge.
    [dc25badge.kicad_pcb]
2017-05-31 Move to 12mil vias.
    [dc25badge-B.Cu.gbr, dc25badge-B.Mask.gbr, dc25badge-B.SilkS.gbr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]
2017-06-01 Switch to a 48-LED compact design.
    Squashed commit of the following:
    commit 6f3d96a4927b58100b9ba94752feefb272124e74
    Author: David Tomaschik <david@systemoverlord.com>
    Date: Thu Jun 1 00:38:57 2017 -0700
    Update notes.
    commit 8834e21676bcc6d408b77b676d72b46c0c38b607
    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
    [LEDs.sch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]
2017-06-02 Initial framework.
2017-06-03 Should be a USB CDC device now.
2017-06-04 SPI looks right on logic analyzer.
2017-06-04 Red LEDs work.
2017-06-04 Pattern framework start.
    [dc25badge.kicad_pcb]
2017-06-04 Switch to async SPI.
2017-06-04 Remove use of CS line.
    [dc25badge.kicad_pcb, dc25badge.sch]
2017-06-04 Add some noise isolation around SPI lines.
    [dc25badge.kicad_pcb]
2017-06-04 Add indicator LED.
    [LEDs.sch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]
2017-06-05 Working timer setup.
2017-06-05 PCB with LED.
    [dc25badge.kicad_pcb]
2017-06-09 Migrate schematic/PCB changes.
    [LEDs.sch, dc25badge.kicad_pcb, dc25badge.sch]
2017-06-09 Add proper button handling support.
    commit b09c200419337edb0ed3439eb5f00ea40777bae3
    Date: Thu Jun 8 19:01:07 2017 -0700
    Button handlers.
    commit 2d1f87d350685d3ec55d109bd5e74c913b28586c
    Date: Thu Jun 8 18:35:55 2017 -0700
    Debounce handler fixed.
    commit a46c87dc804c95a817e12b77fcd806f06aae0592
    Date: Thu Jun 8 17:55:51 2017 -0700
    Different PINMUX.
    commit 326e30240d9baf523002039139fc49dc5ef7f3ef
    Date: Thu Jun 8 17:53:37 2017 -0700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
    [protospin.sch]
2017-06-09 More cap for noise.
    [LEDs.sch, dc25badge.kicad_pcb, dc25badge.sch]
2017-06-10 Add option for anti-ringing resistors.
    [LEDs.sch, dc25badge.kicad_pcb, dc25badge.sch]
2017-06-10 BOM bump.
    [dc25badge.bom.csv, dc25badge.sch]
2017-06-10 Update board.
    [LEDs.sch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]
2017-06-10 This does not work because of asyync interrupts.
    [apa102c.c]
2017-06-10 Do not do all the work in interrupt handlers.
2017-06-11 Code now flows correctly.
    [apa102c.c, config.h, main.c]
2017-06-11 Use 48MHz DPLL for main clock instead of 8MHz RC oscillator.
    [conf_clocks.h]
2017-06-24 Move components to not be in the way.
    [LEDs.sch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]
2017-06-24 Add jumper to bypass fet.
    [dc25badge-B.Cu.gbr, dc25badge-B.Mask.gbr, dc25badge-B.SilkS.gbr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]
2017-06-24 Fix jumper footprint.
    [dc25badge-B.Cu.gbr, dc25badge-B.Mask.gbr, dc25badge-B.SilkS.gbr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]
2017-06-24 No drill map.
    [dc25badge-drl_map.gbr]
2017-06-25 Silkscreen fixes.
    [dc25badge-B.Cu.gbr, dc25badge-B.Mask.gbr, dc25badge-B.SilkS.gbr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]
2017-06-29 Use protel file extensions.
    [dc25badge-B.Cu.gbl, dc25badge-B.Mask.gbs, dc25badge-B.SilkS.gbo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]
2017-07-09 Change bootloader LED.
2017-07-23 Fix jumper.
    [dc25badge.sch]
2017-08-01 Add PDF of schematic.
2017-08-01 Update BOM.
    [dc25badge.bom.csv]
